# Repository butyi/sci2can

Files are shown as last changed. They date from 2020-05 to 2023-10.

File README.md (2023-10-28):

# sci2can

SCI to CAN gateway

## Introduction

This project was developed to receive large data packets from SCI
(RS232 UART without MAX232 line driver) and forward data to CAN
to be available on CAN based tool-chain for analysis purpose.

I decided, this is the perfect moment to get use S08D family, because this
supports faster SCI baud rates than GZ family what I know well.
Therefore I searched my dusty DEMO9S08DZ60 demo board in the deep of cupboard.

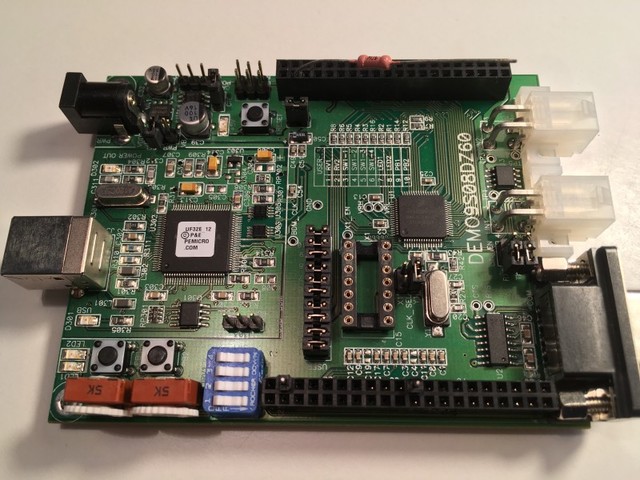
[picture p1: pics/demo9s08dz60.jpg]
demo9s08dz60


## Software

Software is pure assembly code. Funny, it is just 454 bytes long.

### Modules

To understand my description below you may need to look at the related part in
[processor reference manual](https://www.nxp.com/docs/en/data-sheet/MC9S08DZ60.pdf).

#### Central Processor Unit (S08CPUV3)
 
Regarding assembly commands read
[HCS08RMV1.pdf](https://www.nxp.com/docs/en/reference-manual/HCS08RMV1.pdf).
Now (when I am writing this) it is not available on this link even though
I have downloaded from here some weeks before. I have stored it
[here](https://github.com/butyi/sci2can/raw/master/hw/HCS08RMV1.pdf).

My most often read parts are
- Instruction Set Summary (from page 121)
- Branch summary table on sheet of BRA instruction (page 232)

#### Parallel Input/Output Control

To prevent extra current consumption caused by flying not connected input ports,
all ports shall be configured as output. I have configured ports to low level
output by default.
There are only some exceptions for the used ports, where this default
initialization is not proper. For example inputs pins.
This default initialization is proper for FET and OSCILL_SUPP pins, so there is
no specific code for these pins.

#### Multi-purpose Clock Generator (S08MCGV1)

MCG is configured to PEE mode. But this mode can be reached through other modes.
See details in
[AN3499](https://www.nxp.com/docs/en/application-note/AN3499.pdf).
Bus frequency is only 8MHz now, while theoretical maximum is 20MHz.
So here there is improvement potential if software execution is not enough fast.

I have measured bus clock by this code.

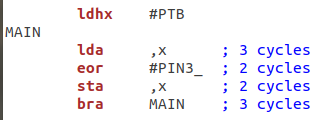
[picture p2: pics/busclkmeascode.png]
busclkmeascode


Really 8 Mhz, because 8 MHz is 125ns, 10 cycle is 1250ns, which can be seen between edges.

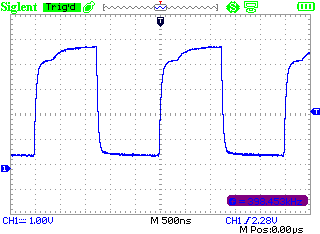
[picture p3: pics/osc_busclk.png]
osc_busclk


#### Serial Communications Interface (S08SCIV4)

SCI clock is driven by Bus Clock. Maximal baud rate is Bus Clock divided by 16.
Since my Bus Clock is 8MHz, maximum baud rate is 500k baud. Now I just need
baud 125k in this application. It is enough to enable only RX direction.
Data is coming in burst, many bytes immediately after each other. There is
idle period between data bursts.
I use Rx and Idle interrupts. Rx interrupt stores received byte in RAM buffer.
Idle interrupt is invoked when there is one byte long idle state on the serial
line after active period. I use this event to recognize end of data packet
reception. At this moment CAN transmission can be initiated (if packet looks
good) and prepare SCI to next packet.

#### Freescale Controller Area Network (S08MSCANV1)

Regarding CAN clock it is proposed to use external clock directly. With 4MHz
crystal maximum baud rate is 500k baud. This is enough for my needs.
CAN bit consists of 8 time quanta. Sample point is 75% (6+2 tq).
Only transmission is used. Receive related registers are not initialized.
But Tx interrupt is used. Message preparation is done by interrupt routine.
Transmission is triggered by enable Tx interrupt. Then interrupt will send
all CAN messages one after another. Last message disables the interrupt to
stop the transmission of data burst.
Automatic BufOff recovery is configured, there is no other error handling. 
After CAN module initialization, an info message is sent to CAN. This contains
software identification information, like application identifier, software
revision, build date.

can_info_message

### Main loop

#### Structure

Software does not have any operation system. It is not needed, especially
because there no task in main loop. Everything is executed in interrupt
routines.

#### Initialization

Stack, ports, needed modules are initialized one by one.

#### Main activity

The following procedure is executed cyclically.
First SCI Rx interrupt fills up the RAM buffer with data.
After Idle interrupt is called. If amount of received data is proper,
CAN transmission is initialized by enable CAN Tx interrupt.
Then CAN Tx interrupts will send out all data from RAM buffer to CAN.
Last CAN message disables itself (CAN Tx interrupt).
Additional features of hardware is not handled by software yet.

#### Status LED

Meantime RTC interrupt handles the status LED.
The following codes are visible on LED.
- 0001, Short 25% On flash: There is no SCI communication.
- 0011, Medium 50%-50% On-Off flash: Received SCI bytes are not enough.
- 0111, Long 75% On flash: Data cannot be sent to CAN.
- 1111, Always On: Everything are OK, data is forwarded to CAN properly.

#### CAN message structure

The 96 data bytes are transmitted in 12 messages. The CAN ID is the position of
first byte of message in the SCI buffer multiplied by 8. This means
- ID of first message is zero
- ID of second message is 8*8 = 64 dec = 40hex
- ID of third message is 16*8 = 128 dec = 80hex
- ... and so on.

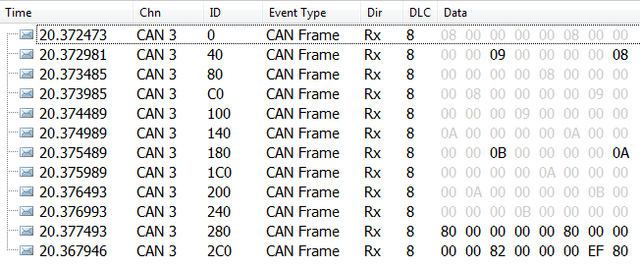
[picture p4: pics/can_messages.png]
can_messages


#### Debug support

If OSCILL_SUPP is enabled by compiler switch, execution timing of software
parts can be watched on not used uC pins by oscilloscope.
Here are oscilloscope screenshots about software activity.

- Blue is SCI line. Bursts are visible.

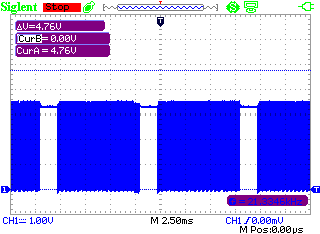
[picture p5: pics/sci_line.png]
SCI_line


- Blue is SCI Bursts. Red is PTE0 pin, where rising edge is first Rx interrupt
after the idle period, faling edge is idle interrupt.

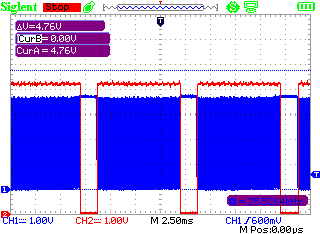
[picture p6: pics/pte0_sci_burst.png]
PTE0_SCI_burst


- Blue is SCI Bursts. Red is PTE1 pin, where rising edge is CAN Tx interrupt
enable, faling edge is end of last CAN Tx interrupt.

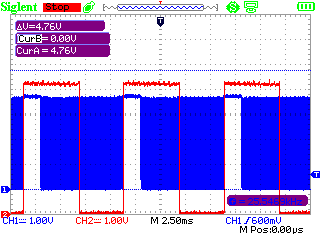
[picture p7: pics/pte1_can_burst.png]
PTE1_CAN_burst


- Blue is SCI Bursts. Red is PTE4 pin, high during SCI Rx interrupt execution.

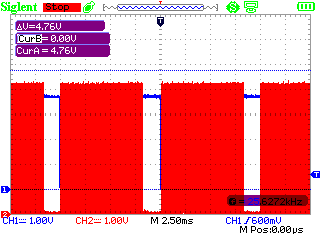
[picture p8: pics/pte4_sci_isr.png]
PTE4_SCI_ISR


- Blue is SCI Bursts. Red is PTE5 pin, high during CAN Tx interrupt execution.

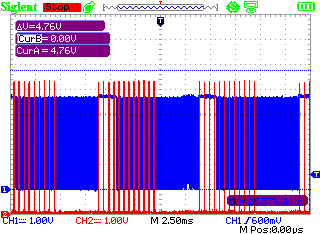
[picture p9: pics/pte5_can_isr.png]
PTE5_CAN_ISR


- Blue is PTE3 pin, high during RTC periodic timer interrupt execution.

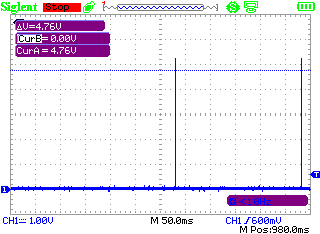
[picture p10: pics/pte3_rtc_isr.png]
PTE3_RTC_ISR


- Blue is PTE3 pin, length of RTC periodic timer interrupt execution.

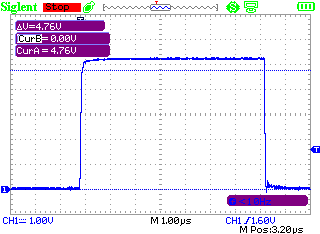
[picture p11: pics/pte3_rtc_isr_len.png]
PTE3_RTC_ISR_len


- Blue is PTE4 pin, length of SCI Rx interrupt execution.

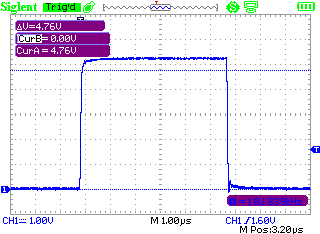
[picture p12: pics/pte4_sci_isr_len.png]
PTE4_SCI_ISR_len


- Blue is PTE5 pin, length of CAN Tx interrupt execution.

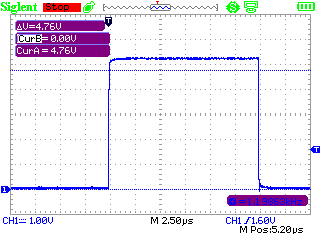
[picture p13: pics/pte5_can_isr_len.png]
PTE5_CAN_ISR_len


- Blue is SCI Rx bursts, red is CAN Tx burst.

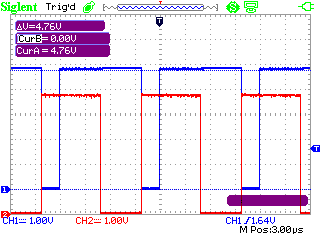
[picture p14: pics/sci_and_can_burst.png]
SCI_and_CAN_burst


- Blue is SCI Rx burst, red is SCI Rx interrupt execution.

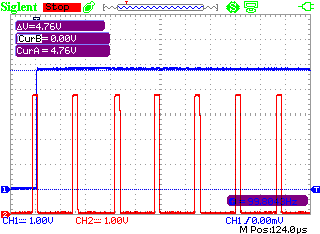
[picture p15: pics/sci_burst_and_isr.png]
SCI_and_CAN_burst


### Compile

- Download assembler from [aspisys.com](http://www.aspisys.com/asm8.htm).
  It works on both Linux and Windows.
- Check out the repo
- Run my bash file `./c`.
  Or run `asm8 prg.asm` on Linux, `asm8.exe prg.asm` on Windows.
- prg.s19 is now ready to download.

### Download

I have already written [downloader/bootloader for DZ family](https://github.com/butyi/dzbl/).

- First download the bootloader (dzbl/prg.s19) by [USBDM](https://sourceforge.net/projects/usbdm/)
- Create CAN or SCI connection between MCU and PC
- Copy `dzdl.py` to `~/bin/` folder and add executable attribute by `chmox +x ~/bin/dzdl.py`. This is only needed once.
- Run bash file `./p`.

## Hardware

After successful operation of software on demo board I decided to design a
specific PCB.

### Requirements

- At least the following connector pins are needed for gateway function:
  - Ground
  - Power supply ( +7V ... +38V )
  - Serial data input line
  - CAN Low
  - CAN High
- Supply power input must support both 12V and 24V systems.
- Supply power reverse polarity protection needed.
- Small power supply dissipation.
- SCI does not need MAX232 driver because there isn't in the transmitter too.
- SCI port must be protected against connect to supply (+38V).
- CAN transceiver is needed.
- CAN Built in terminator resistor is needed.
- Status LED needed with software control.
- Standard BDM port for software download.
- Small board with direct wire connection (not specific connector).

### Microcontroller

I have used MC9S08DZ60. It is enough for such a small project like this.
Assembler, downloader for both Linux and Windows are available for free for this
family. It costs around 1€.
This is my first application with DZ family controller. After finish the
project, and I have to say, I like it! :) It is really better than GZ family.

Refer to
[processor reference manual](https://www.nxp.com/docs/en/data-sheet/MC9S08DZ60.pdf).

### Clock

External Crystal is used for better CAN performances, this is proposed
by uC manufacturer. Passive parts around are also according to datasheet and
similar to development board circuit.
4MHz is enough up to CAN baud rate 500k when external clock is selected.
For 1Mbaud support I selected rather bus clock of bootloader (16MHz), even though external crystal is proposed.
Crystal is now pin type, since via is need anyway, now the pins holes are vias.

### Connector

I used what I have at home. It is two 3 pins screw connector for wires. 

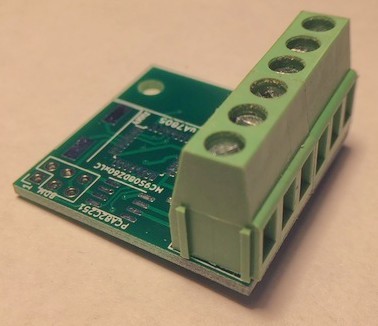
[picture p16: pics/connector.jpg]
connector


The connector is not necessary to be mounted, wires can be soldered directly
into the holes. It saves some money and height.

### Power supply

Power input starts with Ds1 diode for reverse polarity protection.
Same circuit as 7805 replacement was designed on the main board.
Search "7805 replacement switching regulator" on Internet.
It uses ME3116. 1A output, max input voltage is 40V.
I just recognized, transient suppression diode is needed on the input. 
Without this protection the supply could damaged at 24V due sparks during 
switch on. I have choosen SMAJ33A.
There is electrolit capacitor on input voltage.
There are also some filter capacitors on uC supply. 
Once is very close to the microcontroller.

### BDM port

BDM port is like proposed in datasheet. This matches to USBDM developer
interface which I use. Single pin communication line (BKGD) has external pull
up resistor, even if it is not necessary.
Reset pin has simple external pull up resistor and filter capacitor.
This port is only needded for software update.
The connector contains extra pins. Details are below.

### SCI input

SCI input is connected to RX pin of SCI2 module. There are serial resistors
for protection against its connection to 24V.
Next is Ui1 74HC1G125GW as impedance adapter. This provides much higher impedance
input than uC pin.
There is Di2 BZT52C4V7 transient suppressor diode to save further parts of
circuit against high voltage tranzients. 
Especially because PTE port has no built in clamp diode to supply.

When Ui1 is mounted, Ri3 and Ri4 are not needed.
Ri3 and Ri4 are designed when pin is used for normal digit or analogue input. 

Ui1 provides perfect shape and amplitude signal for uC input pin.
Here is a screenshot about shape of SCI signal on the uC pin (RxD1).

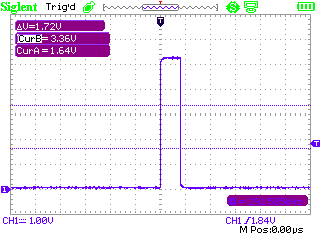
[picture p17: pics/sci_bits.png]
sci_bits


### CAN output

CAN uses PCA82C251 transceiver. Since there will be point-point connection
on this CAN and other side usually does not have terminator resistor,
there is built in CAN line terminator resistor (Rc2) with 100 Ohm.
Why not 120ohm? Good question.
To limit number of different parts, I have tried to use 100ohm, 1k, 10k, 100k,
1M resistors and 10nF, 100nF, 1uF, 10uF capacitors as many places as possible.
I could buy these parts by 1€/5000pcs. To store it, the cheapest solution
is to buy empty creme holder box in the pharmacy. :smile:
Turning back to CAN.
CAN hardware supports high baud rates up to 1MBaud, but does not support CANFD. 

### Status LED

Status LED (D3) is connected to PTD2. Level high on pin will switch on the LED.
LED is controlled by the software.

Status LED and power LED are near to each other on the back of PCB
intentionally. Plastic box have a hole where the LEDs are, and PCB is fixed in
the box by glue gun. This glue is usually enough transparent to be LED light
visible outside while it is still dust resistant.

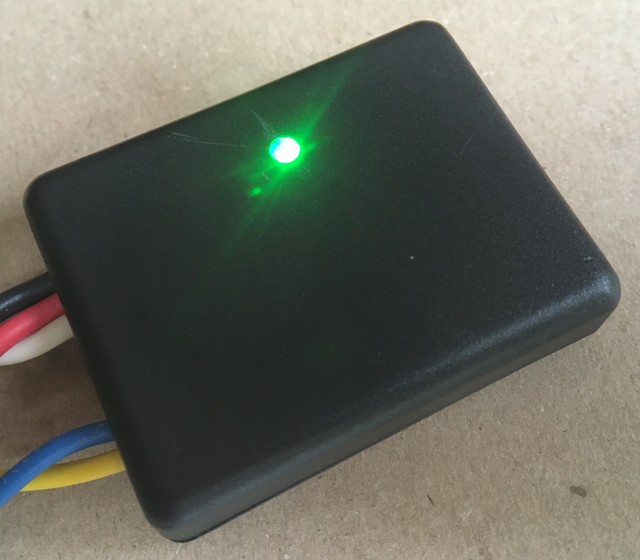
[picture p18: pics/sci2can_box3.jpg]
box3


### Additional features

Board was designed to be usable for other purposes as well, as much as the
board size allows it. Therefore some components and solutions were also
added to hardware. These are not needed for the original function,
but I hope these will be useful for other functions in the future with the same
board. These components are marked by * on the schematic. These are not need to
be mounted for simple gateway function.

#### Inputs

SCI input is also connected to PTA0. It allows to be used as analogue input.
In this case Ri4 was designed to be used as low side of a voltage divider.
If filter is needed, filter capacitor can be soldered on the top of Ri4 or the
zener.
Similar circuit is also available on the other IO pin without pull down resisor.
When IO pins is used as output, input circuit can be used to monitor the output.

#### Outputs

Hardware has two low side FET outputs. These can switch some external loads,
like lamp, buzzer, relay, or similar.
Gate is pulled down to close FET while port is not yet controlled.
FET was intentionally connected to timer output pins, because this makes outputs
pulse and PWM capable.

OUT ports can also be used as timer input if FET is not mounted but instead a
suitable resistor is mounted between source and gate pins of FET. In this case
this resistor together with gate pull down resistor are a voltage divider.
Filter capacitor (if needed) can be soldered on the top of pull down resistor.
Since FETs are connected to timer ports, this way timer can be used for
pulse length measurement, frequency measurement or similar.

#### Supply measurement

Since there was enough place on PCB and remained several not used ports,
voltage divider was designed from power supply input (UZ) and connected to
PTA5 analogue measurement capable port. With this parts supply voltage can
be measured by the software and used for any purpose.

#### BDM extra pins

The original 6 pins connector contains also SCI1 Rx and Tx pins.
This is designed to be used for software update and debug terminal.

I have extended the debugger connector by 4 additional pins. These are now
the IIC/SPI pins as preparation to connect some IIC or SPI display to board.
I use it now for a small 0.96 col OLED IIC display.

### Printed Circuit Board

#### Design

PCB was designed on [KiCad](https://kicad-pcb.org/), which is a free
PCB development environment on works also on Linux.
It works well, I really like to use it. I was so satisfied, I have donated the
project through [Linux Foundation.](https://www.linuxfoundation.org/).
I have exported schematic in PDF for those who do not have KiCad installed.
[Here is schematic](https://github.com/butyi/sci2can/raw/master/hw/sci2can_sch.pdf).

Designed PCB is a small board with size 30x30 mm to fit into mentioned box.
Here are some pictures about the board design in KiCad.

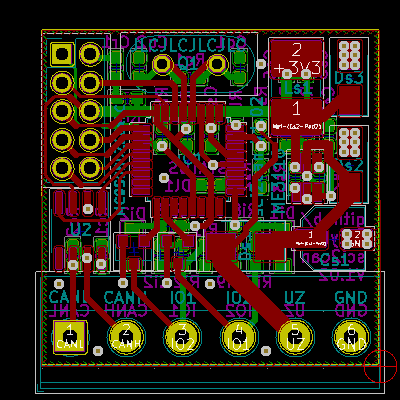
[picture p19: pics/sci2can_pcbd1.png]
pcbd1


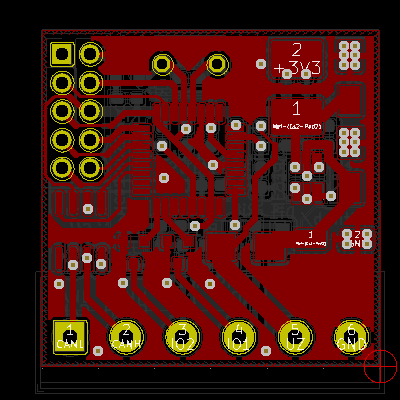
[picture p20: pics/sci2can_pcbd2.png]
pcbd2


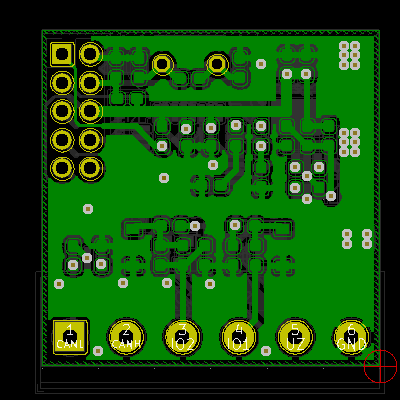
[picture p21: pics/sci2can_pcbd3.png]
pcbd3


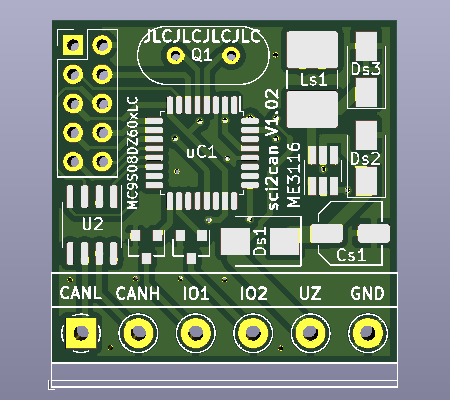
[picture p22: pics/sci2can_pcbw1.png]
pcbw1


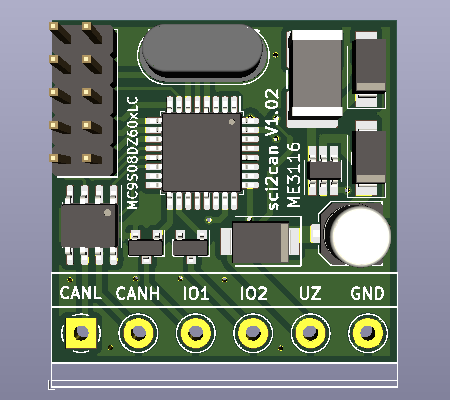
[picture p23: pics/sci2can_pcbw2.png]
pcbw2


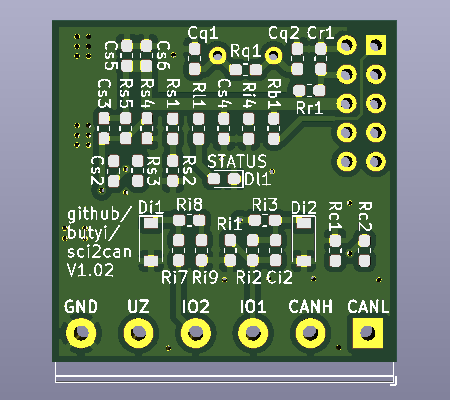
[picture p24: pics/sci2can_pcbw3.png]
pcbw3


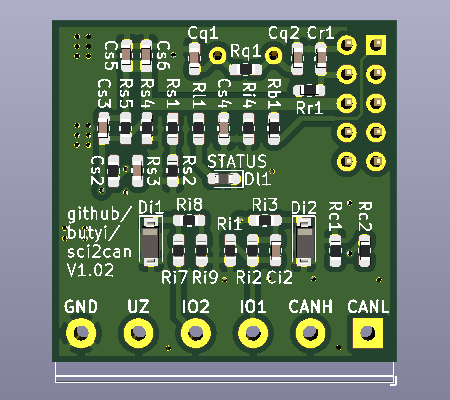
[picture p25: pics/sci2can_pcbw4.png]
pcbw4


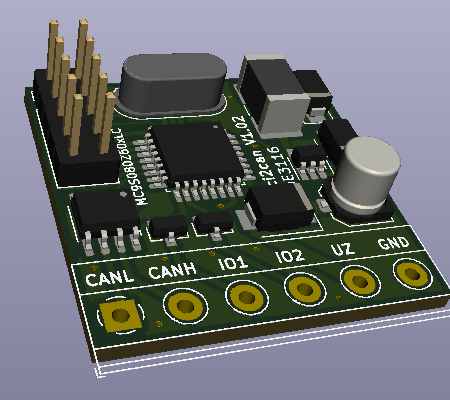
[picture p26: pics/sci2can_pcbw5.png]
pcbw5


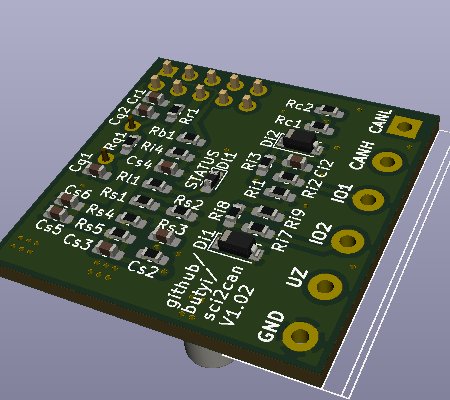
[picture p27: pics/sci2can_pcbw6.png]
pcbw6


#### Production

A-sample PCBs (V1.00) were produced by [SOS PCB Kft.](https://nyakexpressz.hu/).
I was satisfied with quality of production. 

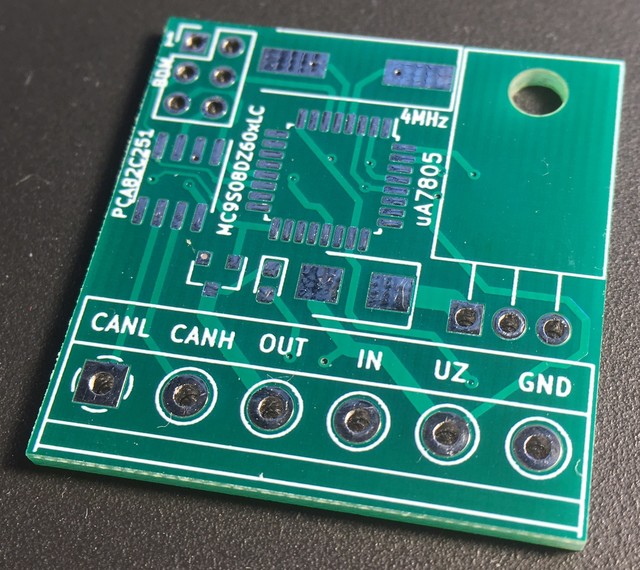
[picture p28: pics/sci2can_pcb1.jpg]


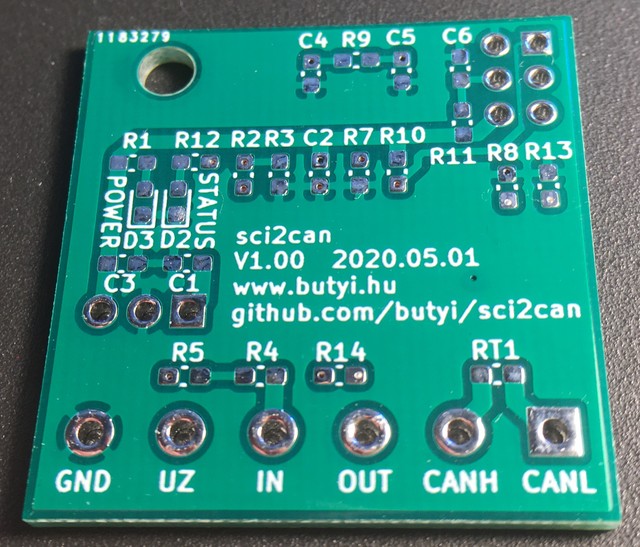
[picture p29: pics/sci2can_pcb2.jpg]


I have ordered second generation PCB from China with SMD mounting.
Result is sufficient.

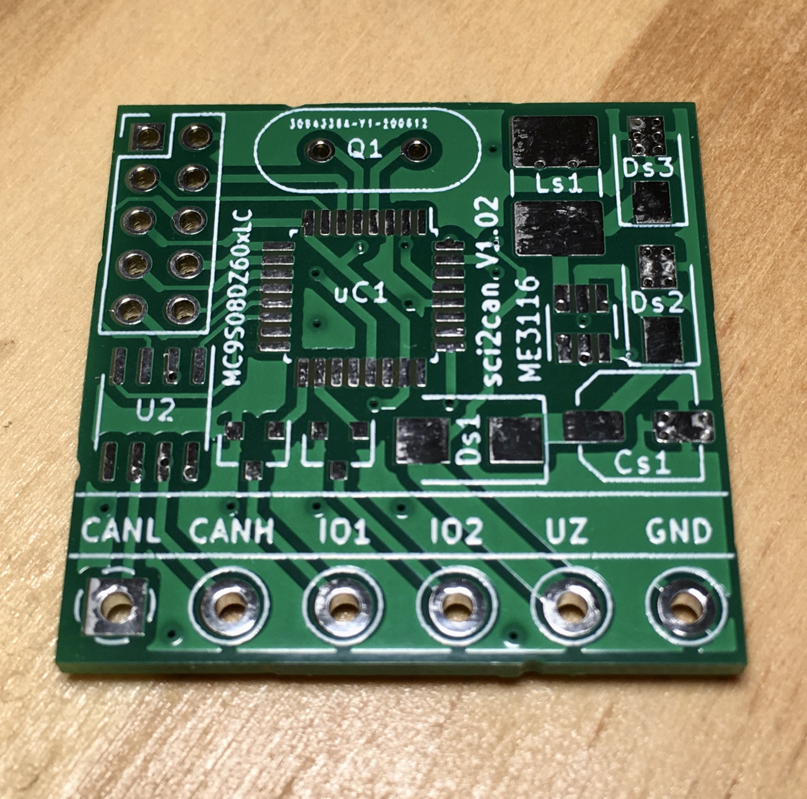
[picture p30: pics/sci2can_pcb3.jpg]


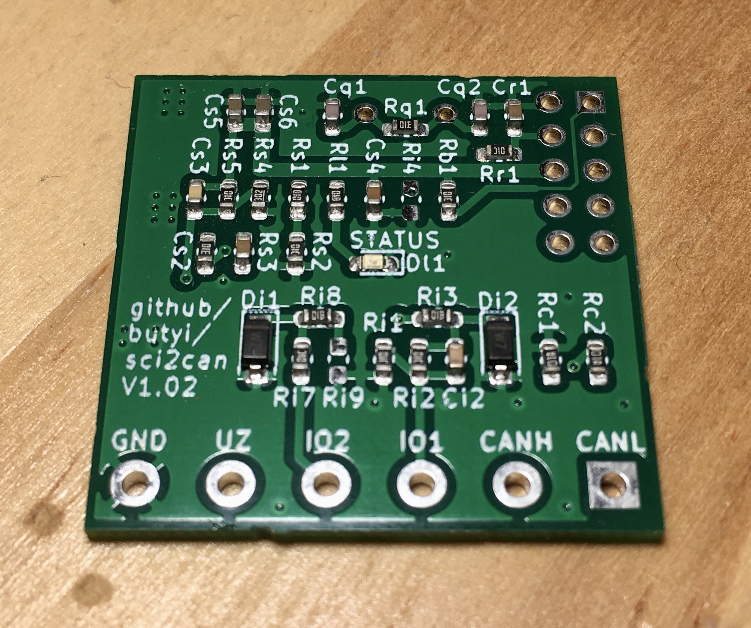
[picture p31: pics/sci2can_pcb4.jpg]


### Mounting

R and C components on the bottom side were mounted by PCB producer.
I have to mount only the up side components by hand.

Note, take care to low resistance of solder paste. Use as less as possible,
and always remove remainings by water.

### Box

Here are pictures about V1.00 prototype.

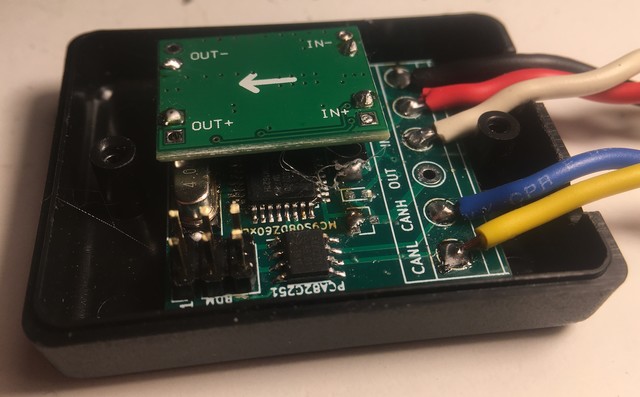
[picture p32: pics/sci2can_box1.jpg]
box1


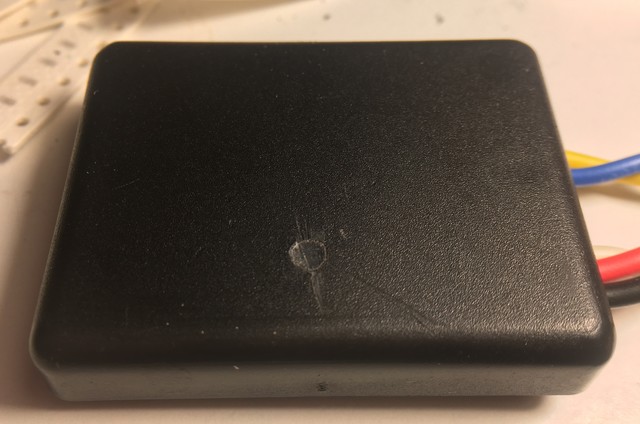
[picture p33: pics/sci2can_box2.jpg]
box2


I have ordered this box for null-series:

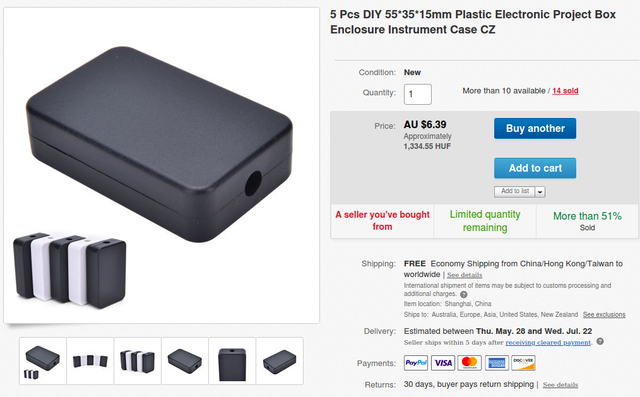
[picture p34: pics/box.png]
box


Simple, cheap, small. Perfect.

Here are pictures about V1.02. This series has a 0.96 inch OLED 128x64 pixels
display and two capacitive touch buttons. Suppressor diodes are still mounted
into IO ports, because these were not yet designed on the board.

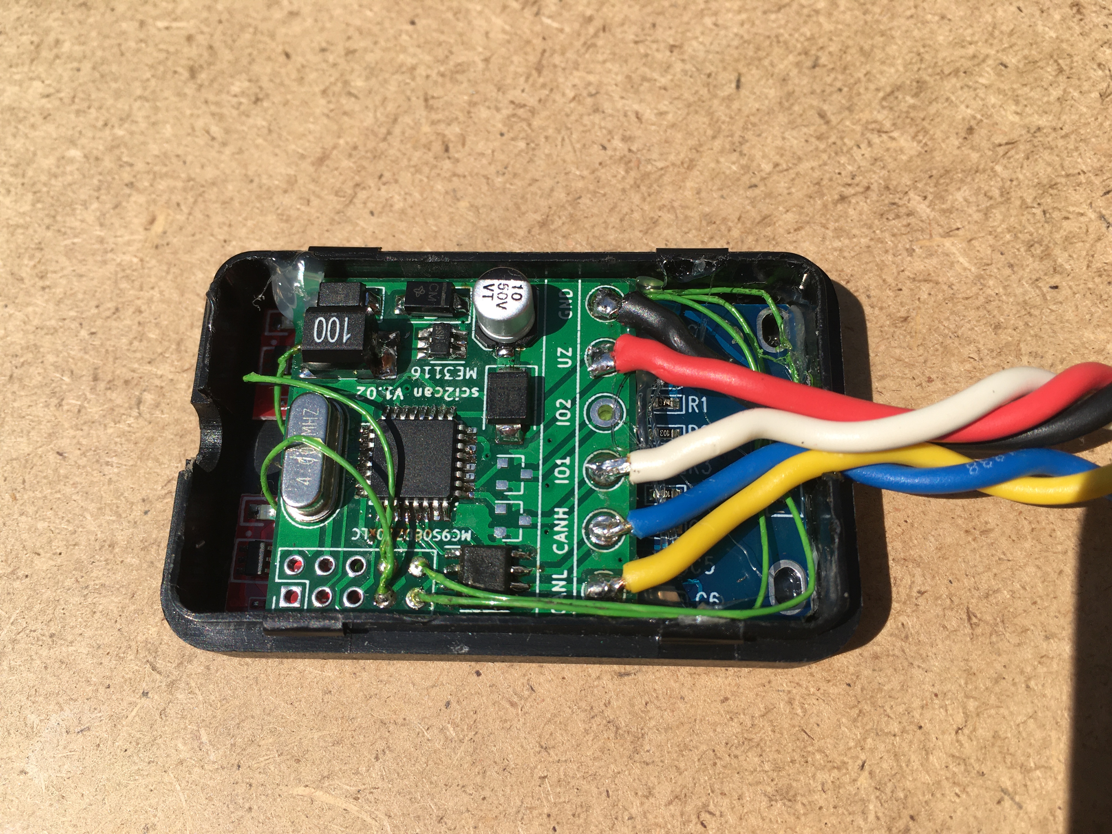
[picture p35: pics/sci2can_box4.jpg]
box4


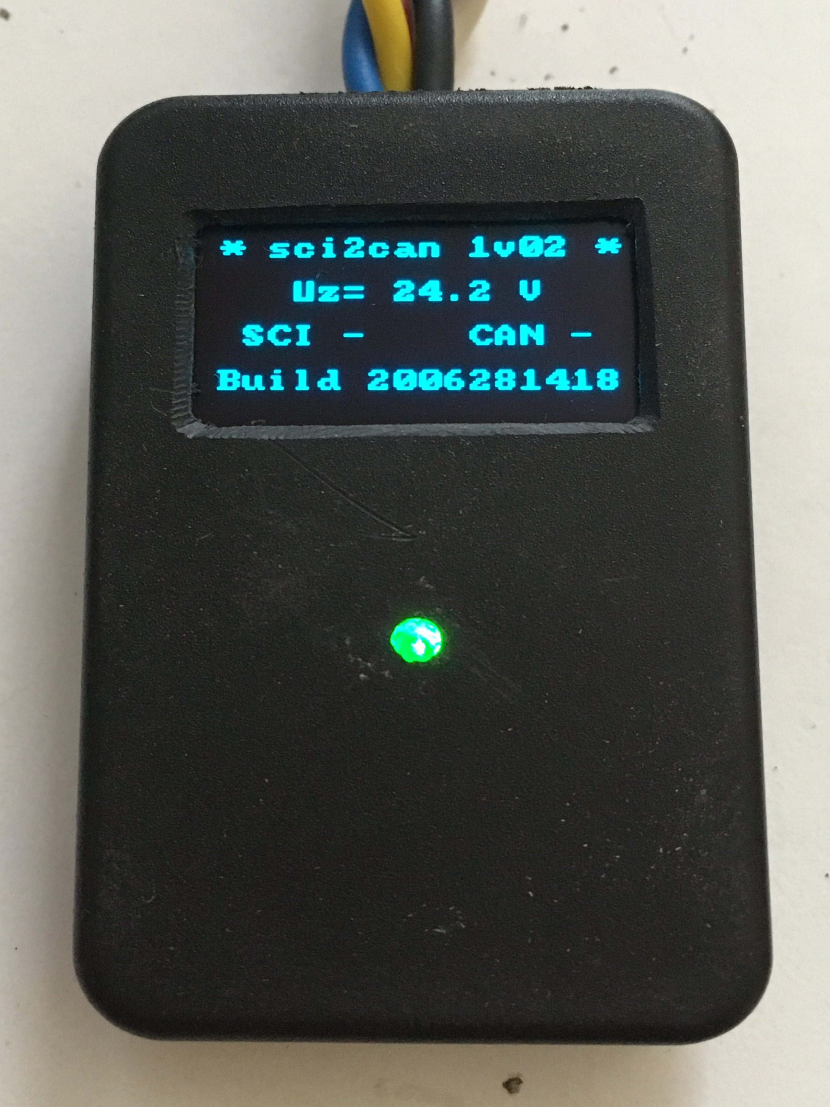
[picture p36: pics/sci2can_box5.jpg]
box5


### Costs

- PCB: 3€
- Microcontroller: 2€ (due to I have bought small amount)
- CAN transceiver: 0.25€
- Switching power supply board: 2€
- Screw connector: 0.5€
- Passive components (all together): 1€
- Box: 1€

Most of them are from [ebay](https://www.ebay.com/).
All together 10€ a product without human costs (development, assembly) and
without profit.

## Workshop

Finally here is a picture about my workshop corner. :smile:

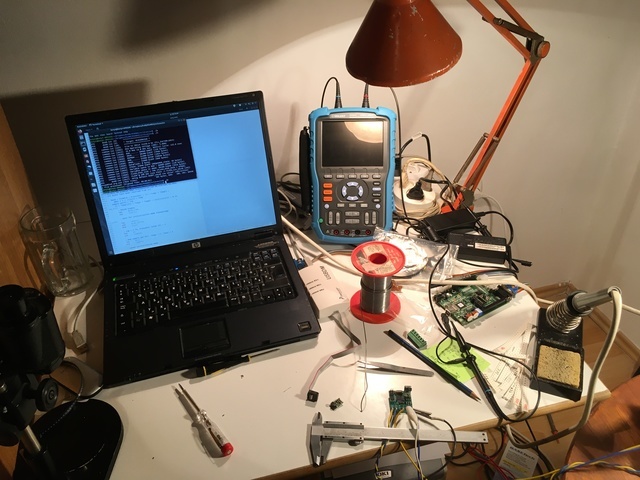
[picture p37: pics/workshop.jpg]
workshop


Left side there is russian microscope, right is also russian soldering iron.

## License

This is free. You can do anything you want with it.
While I am using Linux, I got so many support from free projects,
I am happy if I can give something back to the community.

## Notes

I have used `mogrify -resize 640x640\> *` command to downsize the images.
Here `\>` means only shrink larger images and do not enlarge.

## Keywords

Motorola, Freescale, NXP, MC68HC9S08DZ60, 68HC9S08DZ60, HC9S08DZ60, MC9S08DZ60,
9S08DZ60, HC9S08DZ48, HC9S08DZ32, HC9S08DZ, 9S08DZ, UART, RS232.

###### 2020 Janos BENCSIK

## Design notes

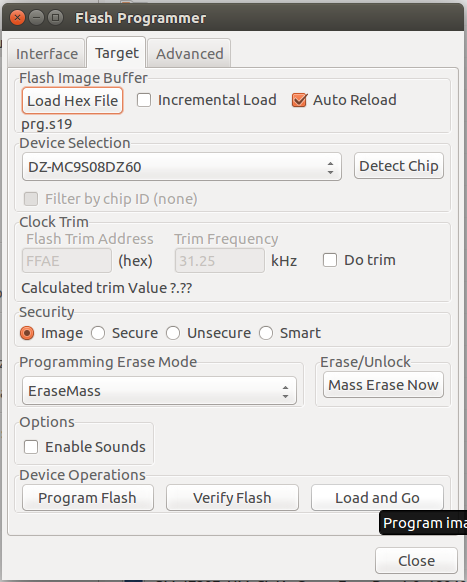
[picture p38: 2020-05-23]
pics/flash_programmer_window.png

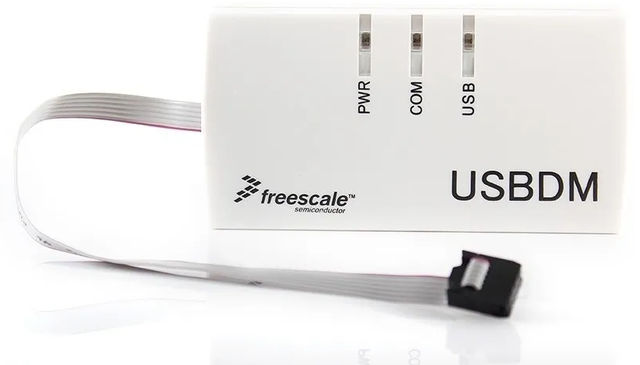
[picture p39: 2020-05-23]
pics/myusbdm.png

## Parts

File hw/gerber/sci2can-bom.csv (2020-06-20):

Designator | Quantity | Value | Footprint | LCSC Part #
Ci2, | 1 | 10nF | 0603 | C57112
Cq1, Cq2, | 2 | 22pF | 0603 | C1653
Cr1, Cs2, Cs4, | 3 | 1uF | 0603 | C15849
Cs3, | 1 | 220pF | 0603 | C1603
Cs5, Cs6, | 2 | 10uF | 0603 | C19702
Di1, Di2, | 2 | BZT52C4V7 | SOD-123 | C173408
Dl1, | 1 | STATUS | LED_0603 | C72043
Rb1, Ri1, Ri2, Ri7, Rr1, Rs2, Rs5, | 7 | 10k | 0603 | C25804
Rc1, Rc2, | 2 | 100 | 0603 | C22775
Ri3, Ri8, Rl1, | 3 | 1k | 0603 | C21190
Rq1, Rs3, | 2 | 1M | 0603 | C22935
Rs1, | 1 | 100k | 0603 | C25803
Rs4, | 1 | 3k2 | 0603 | C4211

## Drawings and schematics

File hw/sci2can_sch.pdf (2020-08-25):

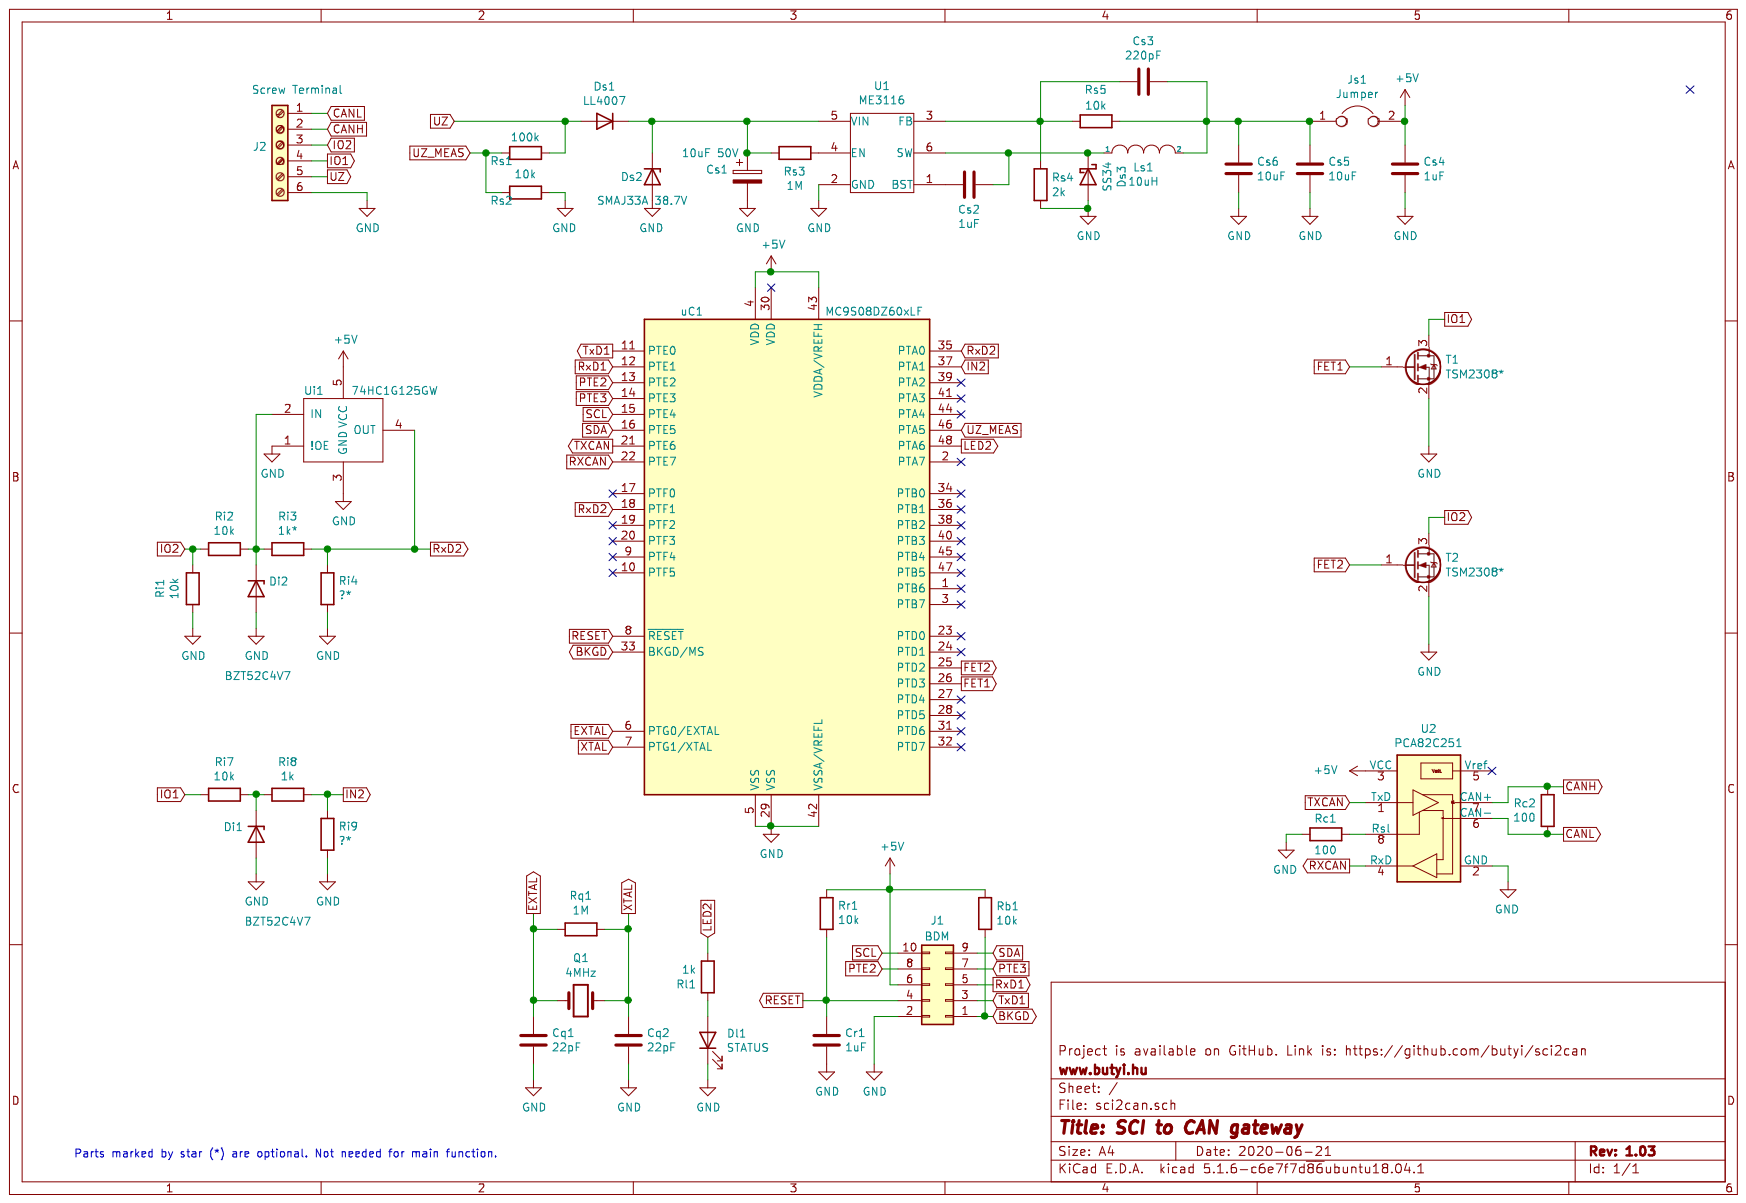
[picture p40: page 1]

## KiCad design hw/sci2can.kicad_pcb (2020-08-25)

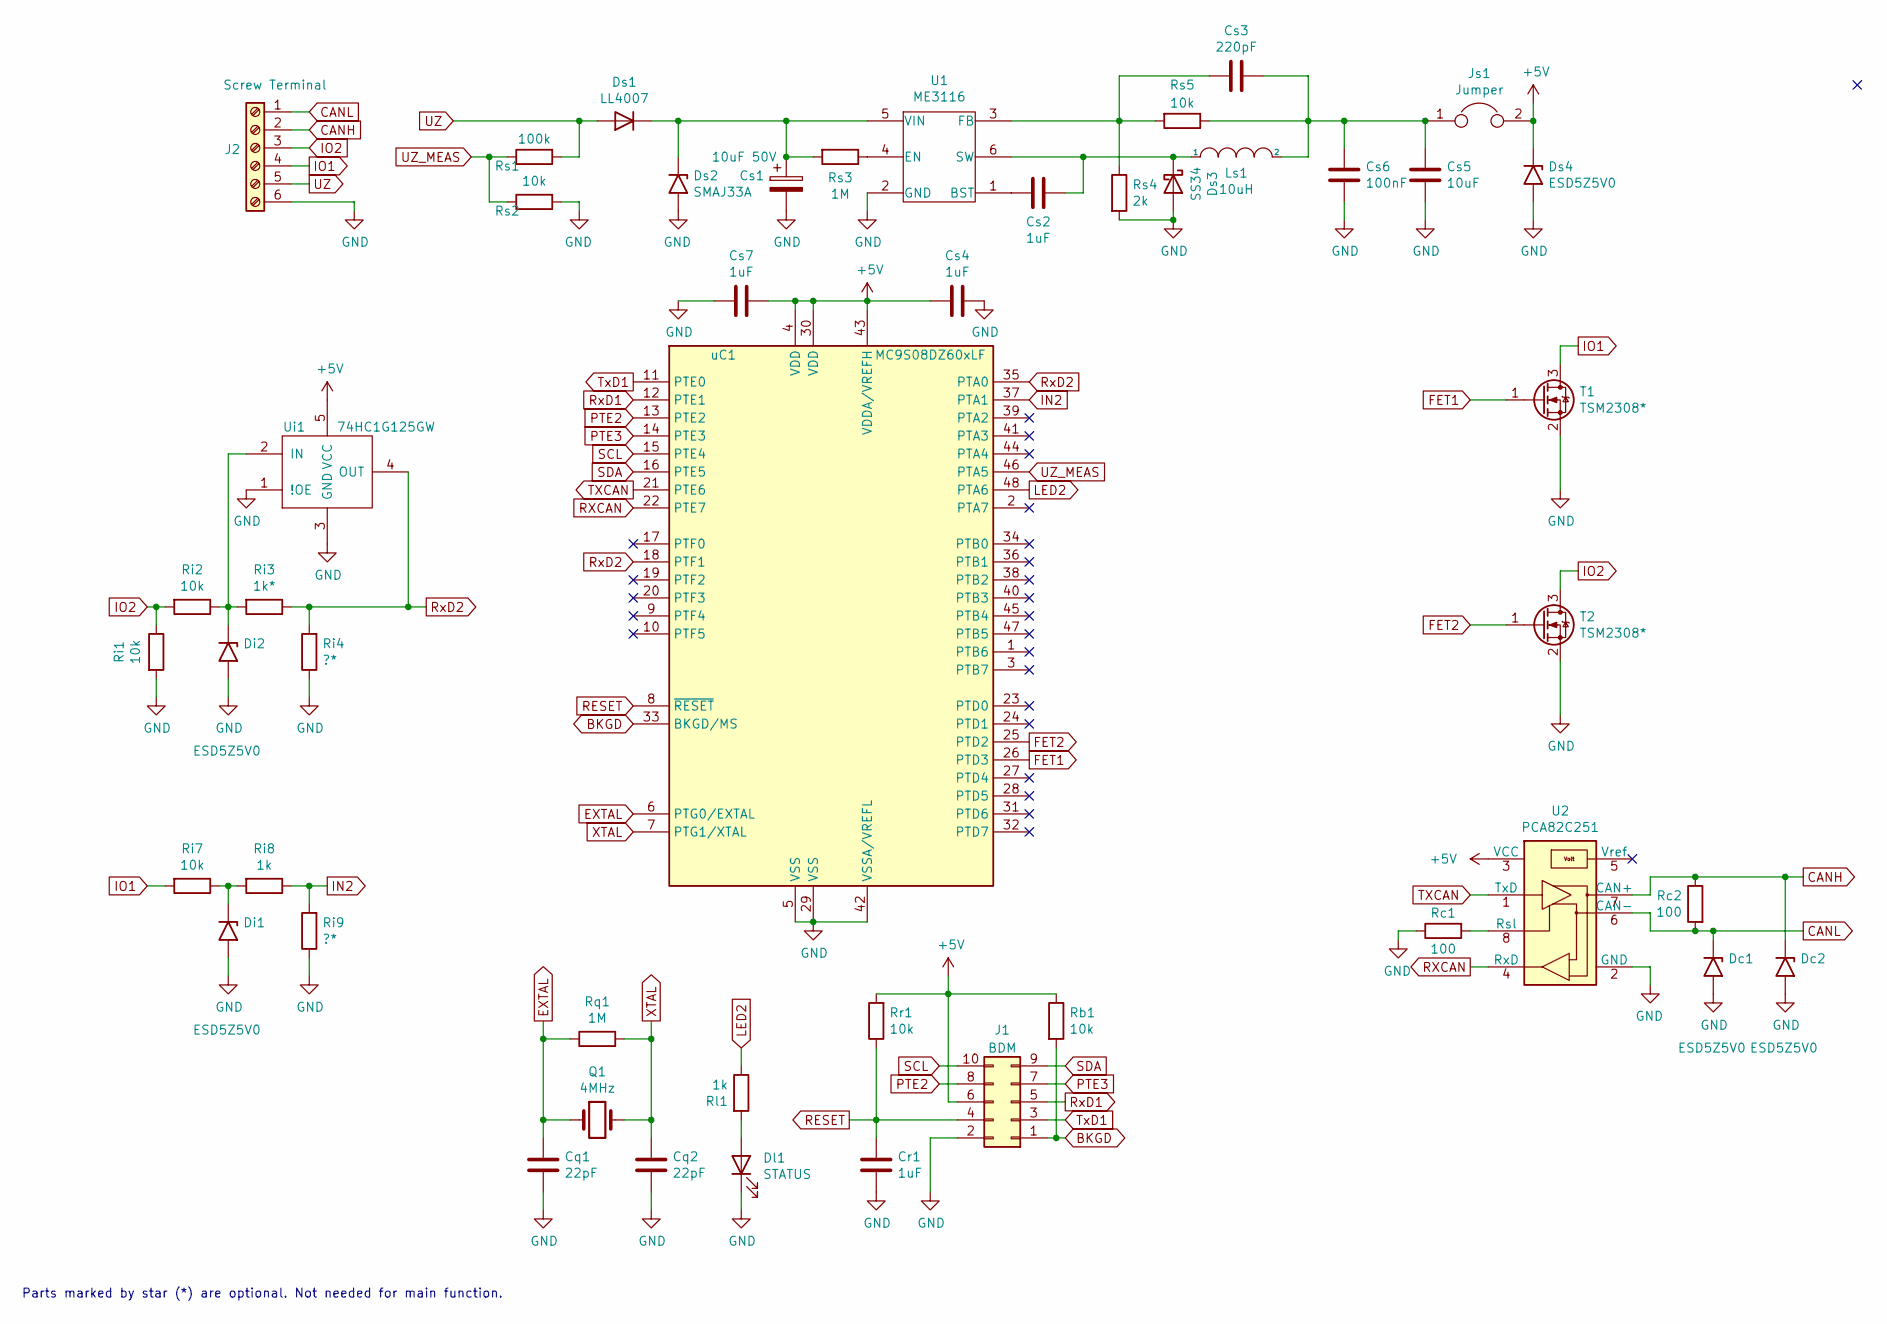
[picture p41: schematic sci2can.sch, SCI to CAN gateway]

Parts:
Cq1, Cq2: 22pF; C_0603_1608Metric_Pad1.05x0.95mm_HandSolder
Cr1: 1uF; C_0603_1608Metric_Pad1.05x0.95mm_HandSolder
Cs1: 10uF 50V; C_Elec_5x5.8
Cs2, Cs4, Cs7: 1uF; C_0603_1608Metric_Pad1.05x0.95mm_HandSolder
Cs3: 220pF; C_0603_1608Metric_Pad1.05x0.95mm_HandSolder
Cs5: 10uF; C_0603_1608Metric_Pad1.05x0.95mm_HandSolder
Cs6: 100nF; C_0603_1608Metric_Pad1.05x0.95mm_HandSolder
Dc1, Dc2: ESD5Z5V0; D_SOD-523
Di1, Di2: ESD5Z5V0; D_SOD-523
Dl1: STATUS; D_0603_1608Metric_Pad1.05x0.95mm_HandSolder
Ds1: LL4007; D_SMB
Ds2: SMAJ33A; D_SMA
Ds3: SS34; D_SMA
Ds4: ESD5Z5V0; D_SOD-523
J1: BDM; PinHeader_2x05_P2.54mm_Vertical
J2: Screw Terminal; TerminalBlock_Phoenix_MKDS-1,5-6_1x06_P5.00mm_Horizontal
Js1: Jumper; SolderJumper-2_P1.3mm_Open_RoundedPad1.0x1.5mm
Ls1: 10uH; L_2816_7142Metric_Pad3.20x4.45mm_HandSolder
Q1: 4MHz; Crystal_HC49-4H_Vertical
Rb1: 10k; R_0603_1608Metric_Pad1.05x0.95mm_HandSolder
Rc1, Rc2: 100; R_0603_1608Metric_Pad1.05x0.95mm_HandSolder
Ri1, Ri2, Ri7: 10k; R_0603_1608Metric_Pad1.05x0.95mm_HandSolder
Ri3: 1k*; R_0603_1608Metric_Pad1.05x0.95mm_HandSolder
Ri4, Ri9: ?*; R_0603_1608Metric_Pad1.05x0.95mm_HandSolder
Ri8: 1k; R_0603_1608Metric_Pad1.05x0.95mm_HandSolder
Rl1: 1k; R_0603_1608Metric_Pad1.05x0.95mm_HandSolder
Rq1: 1M; R_0603_1608Metric_Pad1.05x0.95mm_HandSolder
Rr1: 10k; R_0603_1608Metric_Pad1.05x0.95mm_HandSolder
Rs1: 100k; R_0603_1608Metric_Pad1.05x0.95mm_HandSolder
Rs2, Rs5: 10k; R_0603_1608Metric_Pad1.05x0.95mm_HandSolder
Rs3: 1M; R_0603_1608Metric_Pad1.05x0.95mm_HandSolder
Rs4: 2k; R_0603_1608Metric_Pad1.05x0.95mm_HandSolder
T1, T2: TSM2308*; SOT-23
U1: ME3116; SOT-23-6_Handsoldering
U2: PCA82C251; SOIC-8_3.9x4.9mm_P1.27mm
Ui1: 74HC1G125GW; SOT-353_SC-70-5_Handsoldering
uC1: MC9S08DZ60xLF; LQFP-48_7x7mm_P0.5mm

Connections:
+5V: Cs4.1, Cs7.2, Ds4.1 (A1), J1.6, Js1.2, Rb1.1, Rr1.2, U2.3 (VCC), Ui1.5 (VCC), uC1.4 (VDD), uC1.30 (VDD), uC1.43 (VDDA/VREFH)
BKGD: J1.1, Rb1.2, uC1.33 (BKGD/MS)
CANH: Dc2.1 (A1), J2.2, Rc2.1, U2.7 (CAN+)
CANL: Dc1.1 (A1), J2.1, Rc2.2, U2.6 (CAN-)
EXTAL: Cq1.1, Q1.1, Rq1.1, uC1.6 (PTG0/EXTAL)
FET1: T1.1 (G), uC1.26 (PTD3)
FET2: T2.1 (G), uC1.25 (PTD2)
GND: Cq1.2, Cq2.2, Cr1.2, Cs1.2, Cs4.2, Cs5.2, Cs6.2, Cs7.1, Dc1.2 (A2), Dc2.2 (A2), Di1.2 (A2), Di2.2 (A2), Dl1.1 (K), Ds2.2 (A2), Ds3.2 (A), Ds4.2 (A2), J1.2, J2.6, Rc1.1, Ri1.2, Ri4.1, Ri9.1, Rs2.2, Rs4.2, T1.2 (S), T2.2 (S), U1.2 (GND), U2.2 (GND), Ui1.1 (!OE), Ui1.3 (GND), uC1.5 (VSS), uC1.29 (VSS), uC1.42 (VSSA/VREFL)
IN2: Ri8.1, Ri9.2, uC1.37 (PTA1)
IO1: J2.4, Ri7.2, T1.3 (D)
IO2: J2.3, Ri1.1, Ri2.2, T2.3 (D)
LED2: Rl1.1, uC1.48 (PTA6)
unnamed: Cs1.1, Ds1.1 (K), Ds2.1 (A1), Rs3.2, U1.5 (VIN)
unnamed: Cs2.1, U1.1 (BST)
unnamed: Cs2.2, Ds3.1 (K), Ls1.1, U1.6 (SW)
unnamed: Cs3.1, Rs4.1, Rs5.2, U1.3 (FB)
unnamed: Cs3.2, Cs5.1, Cs6.1, Js1.1, Ls1.2, Rs5.1
unnamed: Di1.1 (A1), Ri7.1, Ri8.2
unnamed: Di2.1 (A1), Ri2.1, Ri3.2, Ui1.2 (IN)
unnamed: Dl1.2 (A), Rl1.2
unnamed: Rc1.2, U2.8 (Rsl)
unnamed: Rs3.1, U1.4 (EN)
PTE2: J1.8, uC1.13 (PTE2)
PTE3: J1.7, uC1.14 (PTE3)
RESET: Cr1.1, J1.4, Rr1.1, uC1.8 (~RESET)
RXCAN: U2.4 (RxD), uC1.22 (PTE7)
RxD1: J1.5, uC1.12 (PTE1)
RxD2: Ri3.1, Ri4.2, Ui1.4 (OUT), uC1.18 (PTF1), uC1.35 (PTA0)
SCL: J1.10, uC1.15 (PTE4)
SDA: J1.9, uC1.16 (PTE5)
TXCAN: U2.1 (TxD), uC1.21 (PTE6)
TxD1: J1.3, uC1.11 (PTE0)
UZ: Ds1.2 (A), J2.5, Rs1.2
UZ_MEAS: Rs1.1, Rs2.1, uC1.46 (PTA5)
XTAL: Cq2.1, Q1.2, Rq1.2, uC1.7 (PTG1/XTAL)

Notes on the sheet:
Parts marked by star (*) are optional. Not needed for main function.

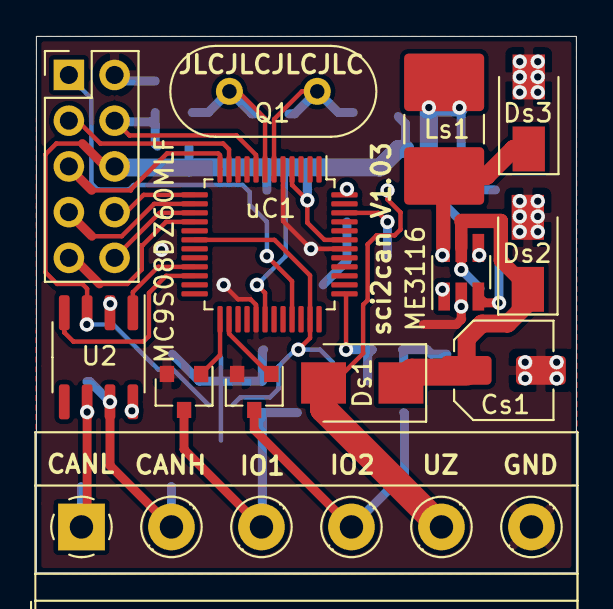
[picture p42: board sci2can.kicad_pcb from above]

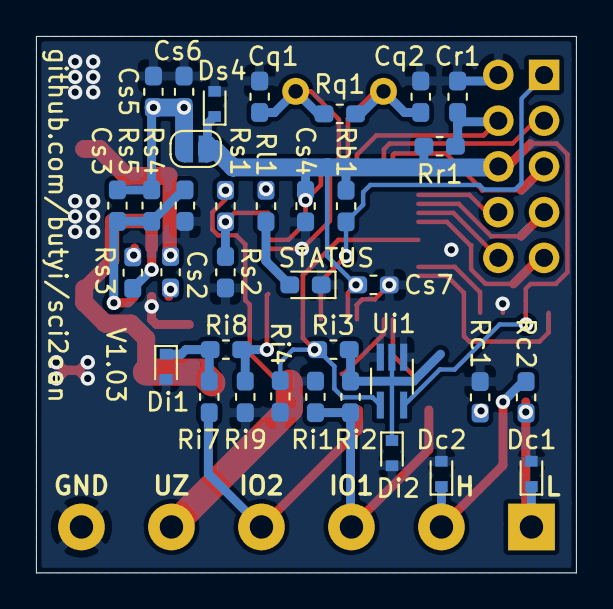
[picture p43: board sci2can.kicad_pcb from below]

Board: 2 copper layers, 30.0 x 29.8 mm, 48 parts (35 on the bottom side), 35 nets.

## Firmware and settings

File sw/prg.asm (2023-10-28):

; ==============================================================================
; ============================  SCI to CAN gateway  ============================
; ==============================================================================
; Details: https://github.com/butyi/sci2can/
; ==============================================================================
#include "dz60.inc"
; ===================== CONFIG =================================================

;MY_PROTOTYPE	def	1       ; Define for my first prototype hardware

APPLICATION     equ     0       ; Gateway applications ID (0: github example)
SW_REV          equ     3       ; Software revison
BUILD_DATE_YH   equ     $20     ; ${:year/100}
BUILD_DATE_YL   equ     $23     ; ${:year-2000}
BUILD_DATE_MO   equ     $10     ; ${:month}
BUILD_DATE_DA   equ     $28     ; ${:date}
BUILD_DATE_HO   equ     $22     ; ${:hour}
BUILD_DATE_MI   equ     $21     ; ${:min}
;OSCILL_SUPP     equ     1       ; To switch on oscillator support

MAXBUFFLEN      equ     200     ; Max number of bytes in received burst (20 CAN messages)
MINBUFFLEN      equ     10      ; Min number of bytes in received burst (1 CAN messages)

; uC port definitions with line names in schematic
LED2            @pin    PTA,6
CANRX           @pin    PTE,7
CANTX           @pin    PTE,6
RxD1            @pin    PTE,1
RxD1_2          @pin    PTA,0
FET             @pin    PTD,2
#ifdef MY_PROTOTYPE
BTNL            @pin    PTA,2  ; My prototype
BTNR            @pin    PTA,1  ; My prototype
#else
BTNL            @pin    PTE,3
BTNR            @pin    PTE,2
#endif

#ifdef OSCILL_SUPP
; Debug pins to measure execution times (high level) by oscilloscope
OSC_SCIRX       @pin    PTD,0   ; Pin is high during SCI Rx burst
OSC_CANTX       @pin    PTD,1   ; Pin is high during CAN Tx burst
OSC_RTCIT       @pin    PTD,3   ; Pin is high during RTC Interrupt routine
OSC_SCIIT       @pin    PTD,4   ; Pin is high during SCI Rx Interrupt routine
OSC_CANIT       @pin    PTD,5   ; Pin is high during CAN Tx Interrupt routine
#endif

BLCR            def     $FFAC           ; $FF (erased) is default settings
                ; bitnum BLCR_ET,0      ; Enable Terminal
                ; bitnum BLCR_ET,1      ; Enable Welcome string on SCI

; ===================== INCLUDE FILES ==========================================

#include "cop.sub"
#include "mcg.sub"
#include "rtc.sub"
#include "iic.sub"
#include "ssd1780.sub"          ; 0.96" 128x64 OLED display
#include "lib.sub"
#include "sci.sub"
#include "can.sub"
#include "adc.sub"

; ====================  VARIABLES  =============================================
#RAM

uz              ds      2       ; Hysteresis filtered Uz voltage
btns            ds      1       ; Saved button states to detect change

; ====================  PROGRAM START  =========================================
#ROM

bl_config
        org     BLCR            ; BootLoader Configuration Register
        db      $FE             ; Disable Terminal and enable Welcome
        org	bl_config

start:
        sei                     ; disable interrupts

	jsr	COP_Init
        jsr     PTX_Init        ; I/O ports initialization
        jsr     RTC_Init
        jsr     CAN_Init
        jsr     SCI_Init
        jsr     IIC_Init        ; Init IIC for fast clear (~100khz)
        bsr     ADC_Init

        cli                     ; Enable interrupts

        clr     uz              ; Init uz variable
        clr     uz+1
        jsr     update_btns     ; Init btns variable

        jsr     IIC_wfe         ; Wait for end of action list
        jsr     DISP_init       ; Initialize display
        lda     #$00            ; Set position to top-left
        ldhx    #startscreen    ; Get address of string
        jsr     DISP_print      ; Print string
        jsr     IIC_wfe         ; Wait for end of action list
;        jsr     IIC_Slow        ; Slow down IIC for update (~10khz)

main
        jsr     KickCop         ; Update watchdog

        brset   EVERY1SEC.,timeevents,m_onesec ; Check if 1s spent

        jsr     update_btns     ; Test button change
        bne     m_btn_event     ; In case of edge, jump to handle

        mov     #PIN5.,ADCSC1   ; Start Uz voltage measurement
m_meas
        jsr     KickCop         ; Update watchdog
        brclr   COCO.,ADCSC1,m_meas ; Wait for finish Uz measurement

        ldx     #0              ; Load uz to arit32
        stx     arit32
        stx     arit32+1
        lda     uz
        sta     arit32+2
        lda     uz+1
        sta     arit32+3

        stx     yy              ; *=255
        stx     yy+1
        stx     yy+2
        lda     #255
        sta     yy+3

        jsr     szor16bit

        ldx     #0              ; /=256
        stx     yy
        stx     yy+1
        lda     #1
        sta     yy+2
        stx     yy+3

        jsr     oszt32bit

        lda     arit32+3        ; +=ADCRL
        add     ADCRL
        sta     uz+1
        lda     arit32+2
        adc     #0
        sta     uz              ; Save back to uz

        bra     main            ; Repeat main cycle

m_onesec                        ; This path called once in every sec
        bclr    EVERY1SEC.,timeevents ; Clear event flag

        lda     uz              ; Load high byte

#ifdef MY_PROTOTYPE
        ldx     #18             ; *=18  ;My prototype
#else
        ldx     #55             ; *=55
#endif
        mul

        pshx
        pulh
#ifdef MY_PROTOTYPE
        ldx     #10             ; /=10  ;My prototype
#else
        ldx     #30             ; /=30
#endif
        div

        clrh
        ldx     #1              ; Length of fractional part is 1 digit
        mov     #5,str_bufidx   ; Set length of string
        jsr     str_val         ; Convert value to string
        lda     #$26            ; Screen position
        jsr     DISP_print      ; Print string

        ; Update SCI status
        ldhx    #ok_err_str
        brclr   SCIPACK_LED.,led_flags,m_sci_err
        aix     #2
m_sci_err
        lda     #$45            ; Screen position
        jsr     DISP_print      ; Print string

        ; Update CAN status
        ldhx    #ok_err_str
        brclr   CANSENT_LED.,led_flags,m_can_err
        aix     #2
m_can_err
        lda     #$4E            ; Screen position
        jsr     DISP_print      ; Print string

        jmp     main
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

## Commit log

2020-05-23 Initial revision
    [sci2can-B_Cu.gbr, sci2can-B_Mask.gbr, sci2can-B_Paste.gbr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]
2020-06-20 hw 1v02
    [sci2can-B_Cu.gbr, sci2can-B_Mask.gbr, sci2can-B_Paste.gbr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]
2020-08-25 HW SW update, 0.96 inch display
    [sci2can.kicad_pcb, sci2can.sch]
2021-02-26 Button frozzen voltage update fixed
    [prg.asm]
2021-02-27 Button pullup enabled
2021-02-28 Buttons active low
